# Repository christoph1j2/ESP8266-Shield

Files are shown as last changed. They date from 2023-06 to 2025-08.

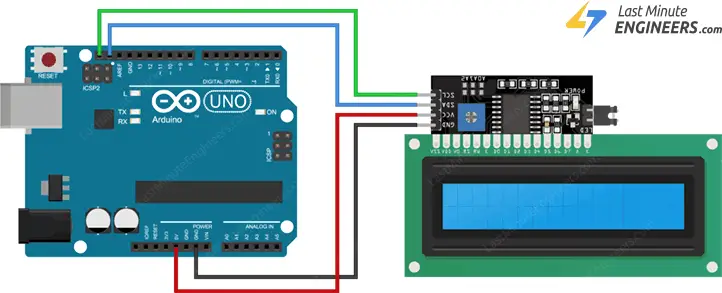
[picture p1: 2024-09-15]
soubory/Wiring-I2C-LCD-Display-with-Arduino.webp

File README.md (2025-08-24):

# ESP8266 Environmental Monitoring Shield

A comprehensive IoT shield for ESP8266 (Wemos D1 R1/R2) that provides environmental monitoring capabilities with multiple sensors, visual indicators, and MQTT connectivity for remote data collection and monitoring.

## 🔋 Features

- **Environmental Sensing**: Temperature monitoring with DS18B20 sensor and light level detection with photoresistor
- **Visual Feedback**: 16-pixel WS2812 LED strip for data visualization and dual status LEDs
- **User Interface**: 16x2 I2C LCD display with rotary encoder navigation and tactile button control
- **Connectivity**: WiFi connectivity with MQTT protocol support for IoT integration
- **Modular Design**: Clean, modular codebase with custom shield library for easy integration and maintenance

## 🛠️ Hardware Components

| Component | Description | Pin Assignment |
|---|---|---|
| **DS18B20** | Waterproof temperature sensor | D0 (ONE_WIRE_BUS) |
| **WS2812** | 16-pixel addressable LED strip | D4 (LED_PIN) |
| **LCD 1602** | I2C 16x2 character display | I2C (SDA/SCL) |
| **Rotary Encoder** | Navigation input device | D6, D7 (ENCODER_PIN1/2) |
| **Push Button** | Menu toggle control | D5 (BUTTON_PIN) |
| **Photoresistor** | Light level sensor | A0 (LDR_PIN) |
| **Status LEDs** | System status indicators | D8, D3 (STATUS_LED_PIN1/2) |

## 📋 Technical Specifications

- **Microcontroller**: ESP8266 (Wemos D1 R1/R2)
- **Operating Voltage**: 3.3V
- **Temperature Range**: -55°C to +125°C (DS18B20)
- **Light Sensing**: 0-1023 ADC range
- **Display**: 16x2 LCD with I2C interface (0x27)
- **LEDs**: 16 individually addressable WS2812 RGB LEDs
- **Communication**: MQTT over WiFi

## 🚀 Quick Start

### Prerequisites

- Arduino IDE with ESP8266 board package
- Required libraries (included in `/shield/knihovny/`):
  - LiquidCrystal_I2C
  - Adafruit_NeoPixel
  - OneWire
  - DallasTemperature
  - ESP8266WiFi
  - PubSubClient

### Installation

1. **Clone the repository**:
   ```bash
   git clone https://github.com/christoph1j2/ESP8266-Shield.git
   cd ESP8266-Shield
   ```

2. **Hardware Setup**:
   - Connect components according to the pin assignments above
   - Refer to `/dokumentace/schema/` for detailed wiring diagrams

3. **Software Configuration**:
   - Open `/shield/shield.ino` in Arduino IDE
   - Update WiFi credentials in the main sketch:
     ```cpp
     const char* ssid = "your_wifi_ssid";
     const char* password = "your_wifi_password";
     const char* mqtt_server = "your_mqtt_broker_ip";
     ```

4. **Upload to ESP8266**:
   - Select your ESP8266 board in Arduino IDE
   - Compile and upload the sketch

## 💡 Usage

### Menu Navigation

The shield features an intuitive menu system:

- **Button Press**: Toggle between menu and measurement mode
- **Encoder**: Navigate between menu options
- **Menu Options**:
  - Measure Light: Display light levels with LED visualization
  - Measure Temperature: Show temperature readings with color-coded LEDs

### LED Visualization

- **Light Measurement**: LED strip displays light intensity (0-8 LEDs per side)
- **Temperature Measurement**: Color-coded temperature indication
- **Status LEDs**: System status and menu state indicators

### MQTT Integration

The shield automatically publishes sensor data to configured MQTT topics for integration with home automation systems, IoT platforms, or data logging services.

## 📁 Project Structure

```
ESP8266-Shield/
├── shield/                    # Main Arduino project
│   ├── shield.ino            # Main sketch file
│   └── knihovny/             # Required libraries
│       └── LeschkaShield/    # Custom shield library
├── dokumentace/              # Documentation
│   ├── fotky/               # Project photos
│   ├── schema/              # Wiring diagrams
│   ├── design/              # Design files
│   └── video/               # Demo videos
└── soubory/                 # Component reference images
```

## 🔧 API Reference

The `LeschkaShield` library provides a clean interface for all shield functionality:

### Core Functions
- `setupStatusLEDs()` - Initialize status LEDs
- `setupLCD()` - Initialize LCD display
- `setupLEDStrip()` - Initialize WS2812 LED strip
- `setupTemperatureSensor()` - Initialize DS18B20 sensor
- `setupButton()` - Initialize push button

### Sensor Reading
- `readTemperature()` - Get temperature in Celsius
- `readLDR()` - Get light level (0-1023)
- `readEncoder()` - Get encoder state
- `readButton()` - Get button state

### Output Control
- `setStatusLEDs(led1, led2)` - Control status LEDs
- `setLEDsForLight(value)` - Visualize light data
- `setLEDsForTemperature(temp)` - Visualize temperature data

## 🤝 Contributing

This project demonstrates professional IoT development practices and modular code architecture. Contributions are welcome for:

- Additional sensor integrations
- Enhanced data visualization
- Protocol extensions (CoAP, HTTP)
- Mobile app integration
- Web dashboard development

## 📄 License

This project is available for educational and commercial use. Please refer to individual library licenses for third-party components.

## 📸 Gallery

### Component References
The `/soubory/` directory contains reference images for all major components including wiring diagrams for the I2C LCD display, DS18B20 temperature sensor, and component specifications for the encoder, WS2812 LED strip, and shield options.

---

*Developed with focus on clean architecture, modularity, and professional IoT development practices.*

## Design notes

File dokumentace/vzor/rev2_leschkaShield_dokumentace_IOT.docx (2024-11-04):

Vyšší odborná škola
a Střední průmyslová škola elektrotechnická
Plzeň, Koterovská 85

Autor práce: Ernst Christoph Leschka

Třída: IV.H

Dne: 05/08/2024

Téma: Vlastní shield pro ESP

# DOKUMENTACE K PROJEKTU IOT

Prohlášení

Prohlašuji, že jsem tuto práci vypracoval samostatně a použil(a) jsem literární prameny a informace, které cituji a uvádím v seznamu použité literatury.

Souhlasím s využitím mé práce učiteli VOŠ a SPŠE Plzeň k výuce.

V Plzni dne: …..................... Podpis: …..........................

Poděkování

Děkuji Mgr. Jiřímu Hautovi za užitečnou zpětnou vazbu k dokumentaci a softwarovému řešení projektu. Také děkuji Ing. Monice Skřivanové za výbornou přípravu na konci třetího ročníku k vyhotovení projektu.

Obsah

# Úvod

Dokumentace se týká custom shieldu na ESP8266, který měří teplotu a taktéž měří svítivost pomocí LDR (Light Dependent Resistor – čili fotorezistor). Cílem této dokumentace je provést čtenáře funkčností jednotlivých komponent a následně řešením, funkcemi a fungováním shieldu, aby tedy bylo jasno co se děje a jak jej použít.

# 1 WeMos D1 R2 UNO ESP8266

Shield je zpracován na mikrokontroler (dále jen MCU) ESP8266, v mém případě specificky na model WeMos D1 R2 UNO ESP8266. Tato MCU mimo jiné na rozdíl například od Arduina umožňuje připojení k Wi-Fi. Jistě si každý povšimne, že na rozdíl od Arduina má méně využitelných pinů, k vyřešení problému nedostatku pinů lze využít expander jako je například PCF8575, který vám pomocí I2C přidá o 16 pinů navíc.

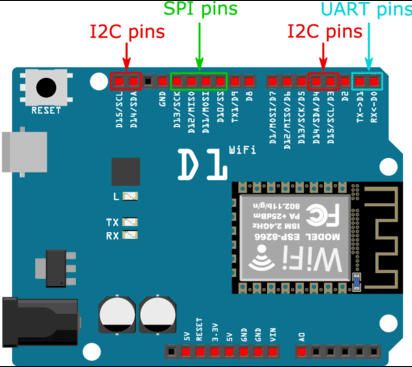
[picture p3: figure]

Obrázek 1: Zobrazení ESP8266 v software Fritzing s popsanými piny [1]

## 1.1 Využití I2C

Neodlučitelnou součástí řešení mého shield je I2C, což je sériový komunikační protokol, který využívá seriál data line (SDA) a seriál clock line (SCL) [2] – viz. Obrázek 1. Nedílná součást shieldu je 16x02 LCD Displej, který komunikuje právě přes I2C. Měl jsem v plánu se taktéž pokusit o vykreslení změny hodnot v čase pomocí grafu na 128x32 OLED displeji, který taktéž komunikuje přes I2C, nicméně se mi bohužel nepodařilo jej zprovoznit. Podobně jsem měl v plánu využít 16bitový expandér pinů PCF8575, jenž taky komunikuje přes I2C, ten jsem ale nakonec nepotřeboval, tak jsem ho z mého řešení eliminoval.

# 2 Hardware řešení

Všechny komponenty jsou na prototypovém shieldu, jelikož si nedokážu představit, jak to zhotovit jinak. Na shieldu jsou přímo připájené LEDky pro zobrazení stavu, enkodér, tlačítko a fotorezistor. Přímo mimo shield leží ještě tepelné čidlo, LCD displej a LED pásky. V podkapitolách bude popis unikátních komponent.

## 2.1 Seznam komponent

Komponenta | Množství | Cena/kus | Link | Cena
Arduino UNO prototype Shield | 1 | 54 Kč | laskakit (https://www.laskakit.cz/arduino-uno-prototype-shield-mini-breadboard/) | 54 Kč
16x2 LCD displej 1602 modrý + I2C převodník | 1 | 98 Kč | laskakit (https://www.laskakit.cz/16x2-lcd-displej-1602-i2c-prevodnik/) | 98 Kč
DS18B20 Digitální vodotěsné čidlo teploty | 1 | 48 Kč | laskakit (https://www.laskakit.cz/dallas-digitalni-vodotesne-cidlo-teploty-ds18b20-1m/) | 48 Kč
8x inteligentní RGB LED NeoPixel pásek, WS2812B | 2 | 28 Kč | laskakit (https://www.laskakit.cz/8x-inteligentni-rgb-led-neopixel-pasek--ws2812b--5050--5v/) | 56 Kč
Fotorezistor 5 mm GL5516 | 1 | 3 Kč | laskakit (https://www.laskakit.cz/fotorezistor-5mm-gl5516/) | 3 Kč
Keyes KY-040 Rotační encoder | 1 | 34 Kč | laskakit (https://www.laskakit.cz/keyes-ky-040-rotacni-encoder-s-tlacitkem/) | 34 Kč
Rezistor 10kΩ | 3 | 1 Kč | laskakit (https://www.laskakit.cz/futaba-1-4w-odpor-10k-5/) | 3 Kč
Rezistor 220Ω | 2 | 1 Kč | laskakit (https://www.laskakit.cz/1-4w-odpor-220r-5/) | 2 Kč
Tlačítko | 1 | 2 Kč | laskakit (https://www.laskakit.cz/tlacitko-6x6x5mm/) | 2 Kč
LED 5 mm | 2 | 1 Kč | laskakit (https://www.laskakit.cz/led-dioda-5mm/?variantId=1130) | 2 Kč
WeMos D1 R2 UNO ESP8266 [^1] | 1 | 178 Kč | laskakit (https://www.laskakit.cz/wemos-d1-r2-uno-esp8266/) | 178 Kč
~~PCF8575 I2C 16 bit I/O~~ ~~Expander~~ [^2] | 1 | 118 Kč | laskakit (https://www.laskakit.cz/pcf8575-i2c-16-bit-i-o-expander/) | 118 Kč
~~0.91" 128x32 OLED displej~~ | 1 | 88 Kč | laskakit (https://www.laskakit.cz/oled-displej-modry-128x32-0-91--i2c/) | 88 Kč
| | | | 686 Kč [^3]

## 2.2 Prototype Shield

Prototype shield je vlastně základ celého shieldu, zjednodušuje konstrukci a po připojení součástek je, lze říci, „Plug-and-Play“. Na ploše shieldu jsou vyhrazená místa pro připojení napájení (5 V) a uzemnění (GND). Taky zde najdeme už připravené tlačítko na reset.

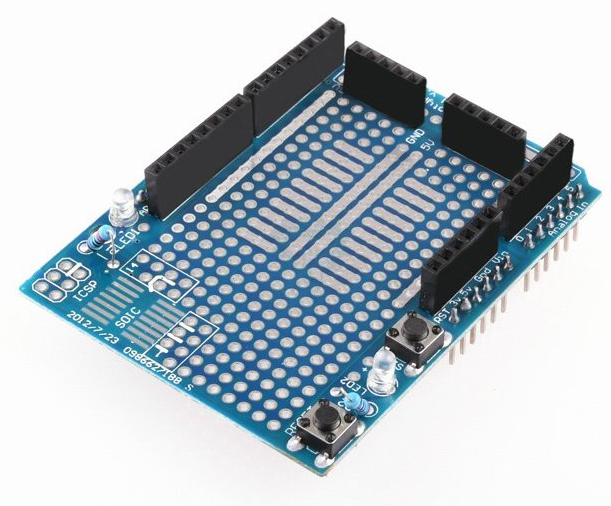
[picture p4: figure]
Obsah obrázku Obvodoví součástka, Elektronická součástka, elektronika, Počítačová komponenta Popis byl vytvořen automaticky

Obrázek 2: Arduino UNO prototype Shield [3]

## 2.3 LCD Displej 16x2 (I2C)

Tento LCD displej má, jak lze poznat podle názvu, rozlišení 16x2, tedy 16 sloupců na dva řádky. Tento displej se primárně používá pro zobrazení znaků či nějakého krátkého textu. V mém případě je to pro zobrazení menu, kde jsou dvě možnosti a poté pro zobrazení hodnoty toho, co právě měříme. Zezadu je potenciometr k úpravě kontrastu.

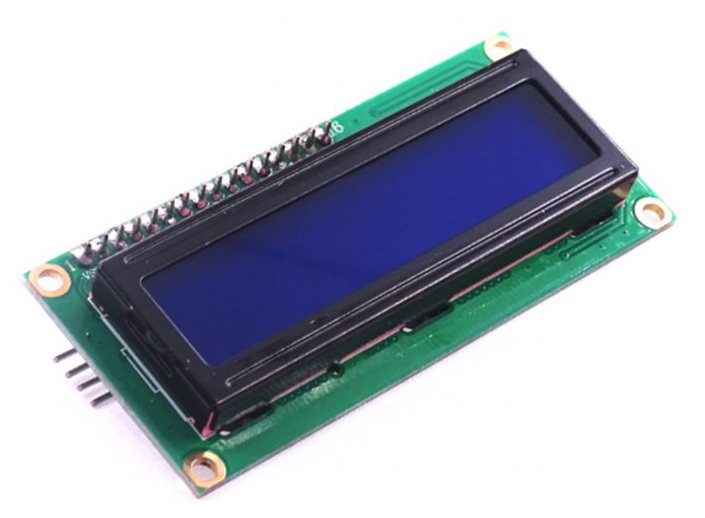
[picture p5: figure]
Obsah obrázku elektronika, Elektronická součástka, Počítačová komponenta, Obvodoví součástka Popis byl vytvořen automaticky

Obrázek 3: 16x2 LCD displej 1602 modrý [4]

### 2.3.1 Schéma zapojení a ukázkový kód I2C 1602 LCD Displeje

V případě I2C verze tohoto displeje je zapojení triviální – uzemnění do GND, napájení VCC do 5 V a následně SDA a SCL do I2C pinů na desce. Na obrázku níže je sice použito Arduino, ale v našem případě zapojení vypadá stejně.

Obrázek 4: I2C zapojení 1602 LCD k Arduinu [5]

Abychom mohli opravdu použít LCD displej musíme použít knihovnu „LiquidCrystal_I2C“, která zahrnuje mnoho funkcí na jeho ovládání. Na obrázku níže vidíme kód, který na první řádce displeje zobrazí text „Hello World!“ a na druhé řádce „LCD Tutorial“. [6]

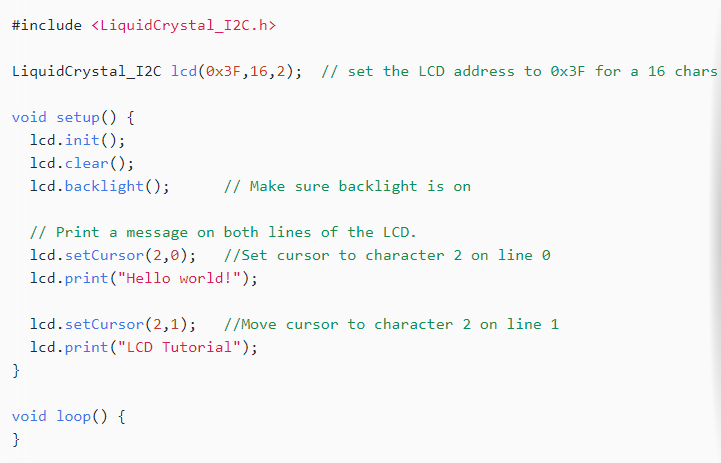
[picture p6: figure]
Obsah obrázku text, snímek obrazovky, Písmo Popis byl vytvořen automaticky

Obrázek 5: Ukázka kódu k LCD [6]

## 2.4 DS18B20 Digitální čidlo teploty

Jedna ze dvou měřených jednotek na shieldu je teplota, tu budeme měřit za pomocí digitálního vodotěsného čidla teploty DS18B20. Čidlo využívá 1wire protokol, který je v principu podobný I2C, ale s nižší rychlostí přenosu dat a delší funkční vzdáleností. [7]

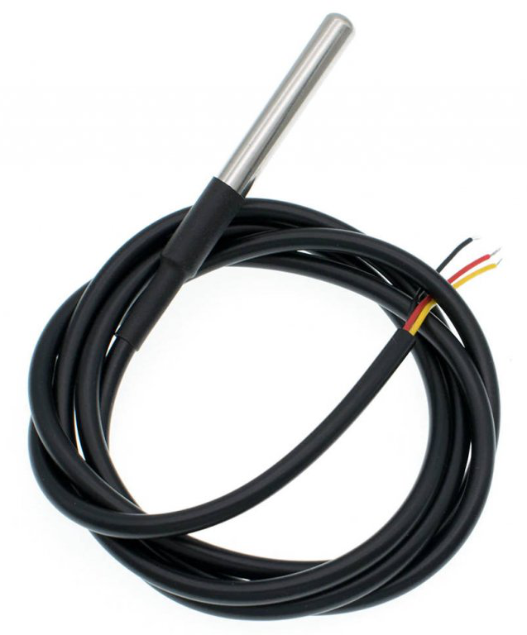
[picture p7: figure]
Obsah obrázku kabel Popis byl vytvořen automaticky se střední mírou spolehlivosti

Obrázek 6: čidlo teploty DS18B20 [8]

### 2.4.1 Schéma zapojení a ukázkový kód DS18B20

Zapojení je intuitivní, uzemnění do GND, napájení VDD do 5 V a datový kabel do digitálního pinu na desce (v případě obrázku D2). Aby přenos dat byl stabilní, přidáme ještě 10kΩ pull-up rezistor mezi datový kabel a napájení.


Obrázek 7: Zapojení čidla teploty k Arduinu [9]

Abychom mohli pomocí čidla měřit, tak budeme potřebovat dvě knihovny – tj. „OneWire“ a „DallasTemperature“. Knihovna OneWire přidává podporu pro 1wire protokol (podobně jako knihovna Wire pro I2C) a knihovna DallasTemperature přidává funkce k ovládání tepelného čidla.

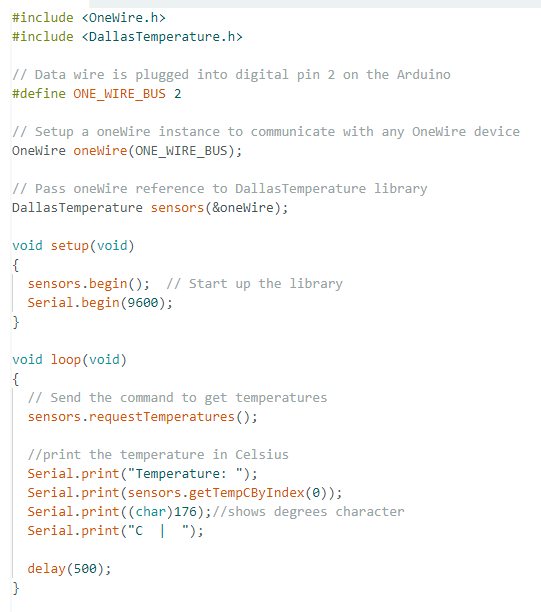
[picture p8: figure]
Obsah obrázku text, snímek obrazovky, Písmo, číslo Popis byl vytvořen automaticky

Obrázek 8: Ukázka kódu k čidlu teploty [10]

## 2.5 RGB LED NeoPixel pásek

Tento LED pásek je tvořen LED diodami WS2812B zapojenými do série. Tyto LED diody mají vestavěný čip s pamětí 3 bajty. Těmi se nastavuje intenzita svitu každé ze tří barev. To umožňuje komunikaci pomocí jednokanálového rozhraní. [11] Pro zobrazení „velikosti“ naměřených hodnotu využijme RGB LED pásku. Při měření světla tedy svítí 0-8 „pixelů“ na pásce podle toho, jakou hodnotu od 0-1024 fotorezistor naměří. Stejně tak u teploty svítí 0-8 „pixelů“ podle toho, jakou hodnotu od -10°C do 70°C naměří tepelné čidlo.

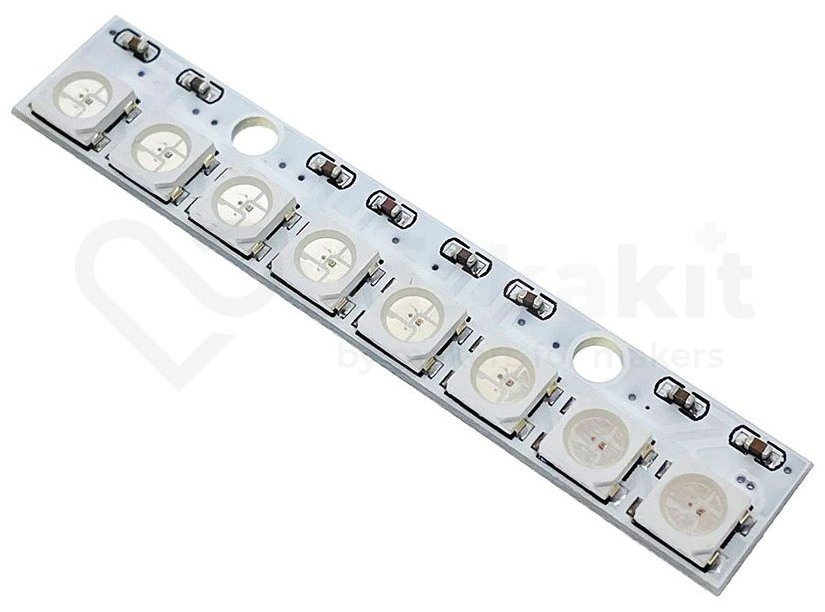
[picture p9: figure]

Obrázek 9: RGB LED NeoPixel pásek [11]

### 2.5.1 Schéma zapojení a ukázkový kód NeoPixel RGB pásku

Opětně triviální zapojení – uzemnění do GND, napájení VCC do 5V a DIN do digital pinu na desce. Chceme-li zapojit více pásek sériově, tak z druhé strany první pásky zapojíme DOUT do druhé pásky DIN.

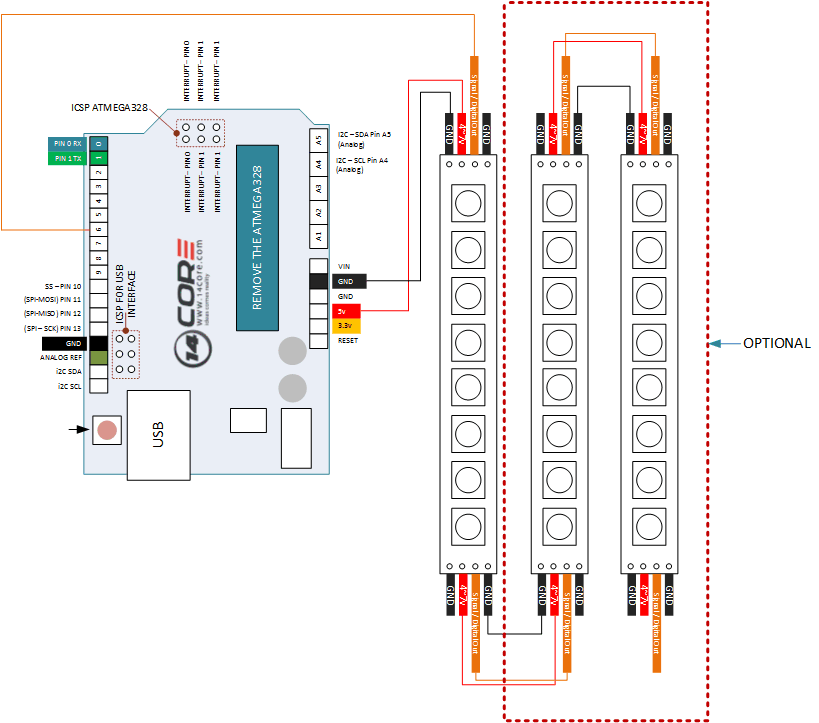
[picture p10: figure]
Obsah obrázku text, diagram, Paralelní, snímek obrazovky Popis byl vytvořen automaticky

Obrázek 10: Zapojení WS2812 LED Pásky [12]

Nyní k ukázce kódu – tento program vytvoří efekt pomalého „nalití“ barvy do pásku dlouhého 1 m s 30 LED/m, bude se cyklicky střídat sedm barev. Po rozsvícení celý pásek plynule pohasne [13]

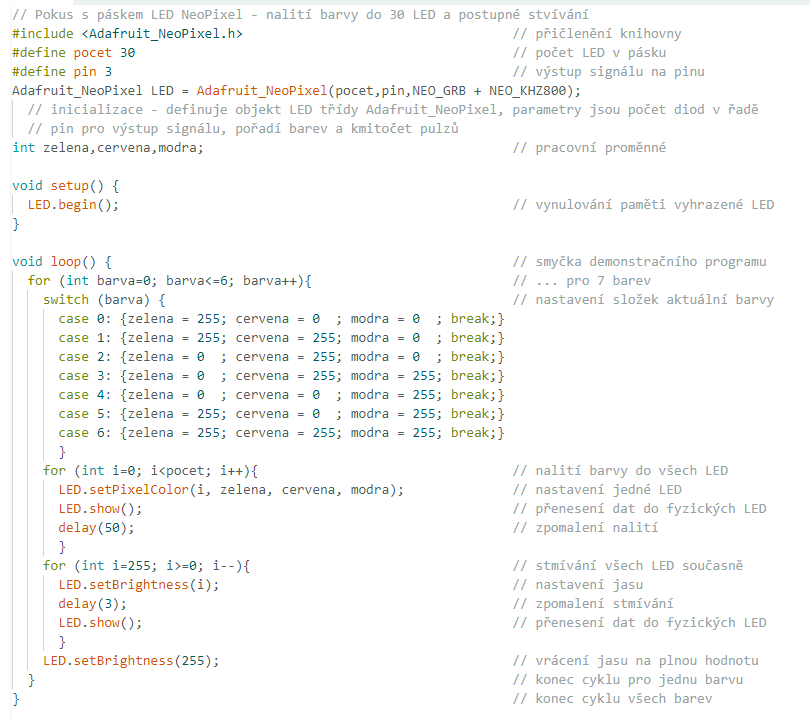
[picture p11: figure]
Obsah obrázku text, snímek obrazovky, číslo, Písmo Popis byl vytvořen automaticky

Obrázek 11: Ukázka kódu k LED pásce [13]

## 2.6 KY-040 Rotační enkodér

Otočný enkodér Keyes KY-040 je rotační vstupní zařízení, které ukazuje, jak moc byl knoflík otočen a jakým směrem se otáčí. Je to skvělá komponenta pro řízení krokových a servomotorů. [14] V našem případě ho využijeme k výběru měřené jednotky v menu.

Obrázek 12: KY-040 Rotační enkodér [15]

### 2.6.1 Schéma zapojení a ukázkový kód enkodéru

Opět nic složitého, uzemnění do GND, napájení do 5V a poté CLK a DT do digital pinů na desce. SW nevyužijeme.

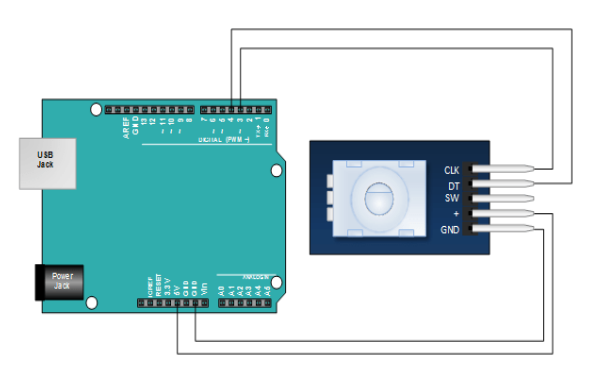
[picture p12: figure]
Obsah obrázku text, Obdélník, snímek obrazovky, design Popis byl vytvořen automaticky

Obrázek 13: Zapojení enkodéru KY-040 do Arduina [14]

Kód testuje klíčové funkce enkodéru, tedy pozici, ve které aktuálně je a možnost zjistit, zda poslední rotace byla ve směru hodinových ručiček či v proti směru. V řešení shieldu takto „komplikovaný“ kód ale nebyl potřeba, jelikož nám stačí dvě hodnoty, tedy např. 1 a 0.

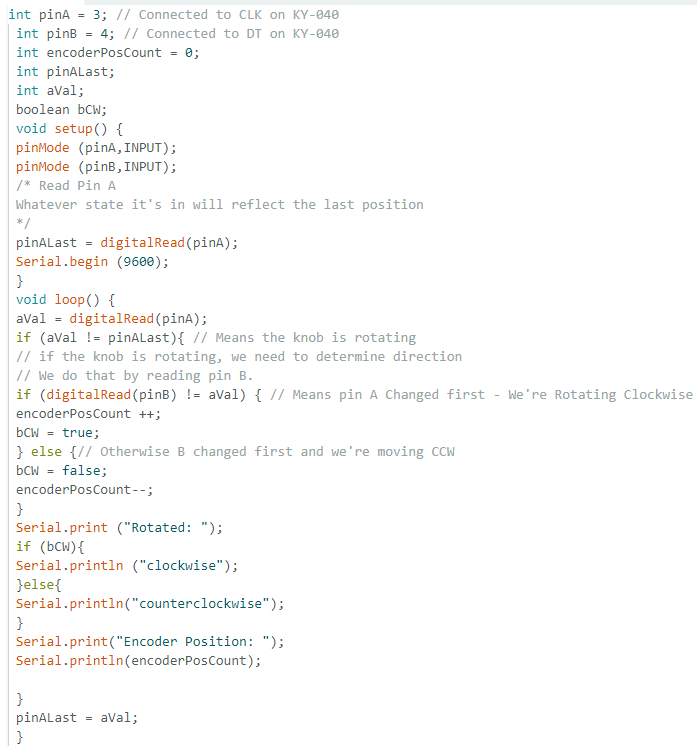
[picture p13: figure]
Obsah obrázku text, snímek obrazovky, dokument Popis byl vytvořen automaticky

Obrázek 14: Ukázka kódu enkodéru KY-040 [14]

## 2.7 Finální hardware řešení shieldu

Poskládáme-li všechny zmíněné komponenty dohromady, vznikne tato finální verze zapojení.

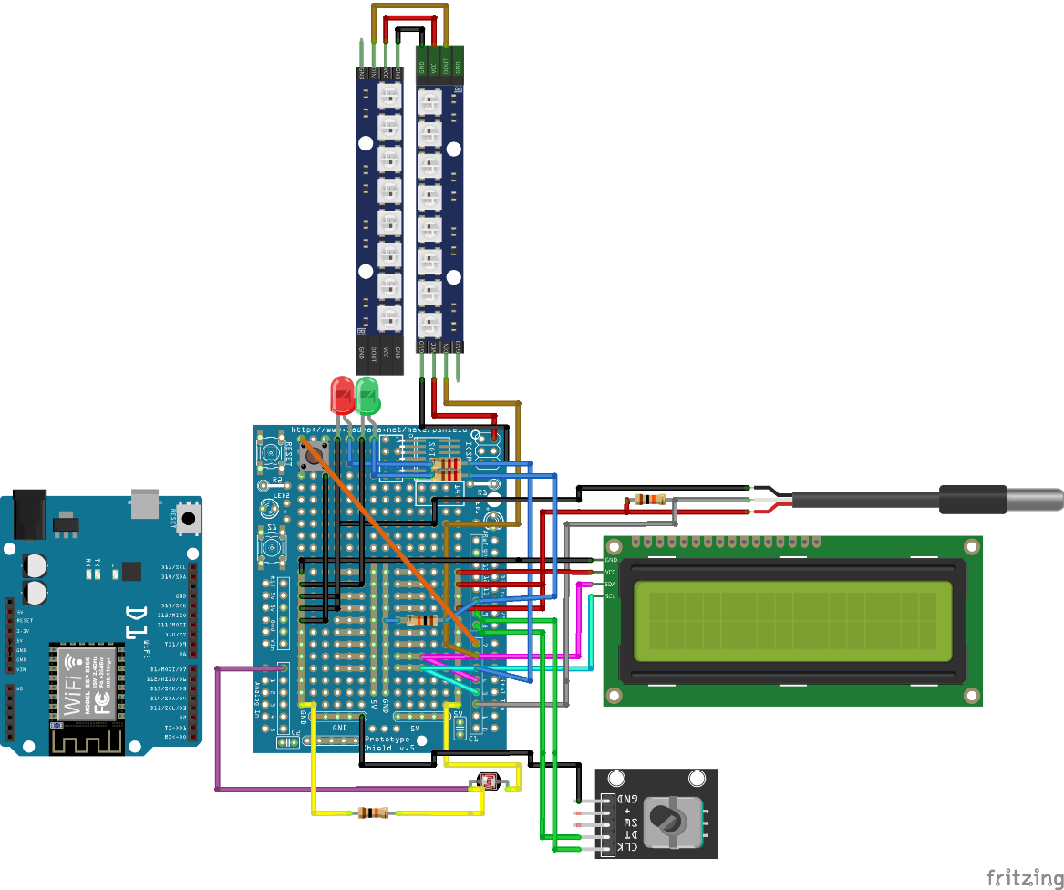
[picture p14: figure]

Obrázek 15: Zapojení shieldu ve Fritzingu [16]

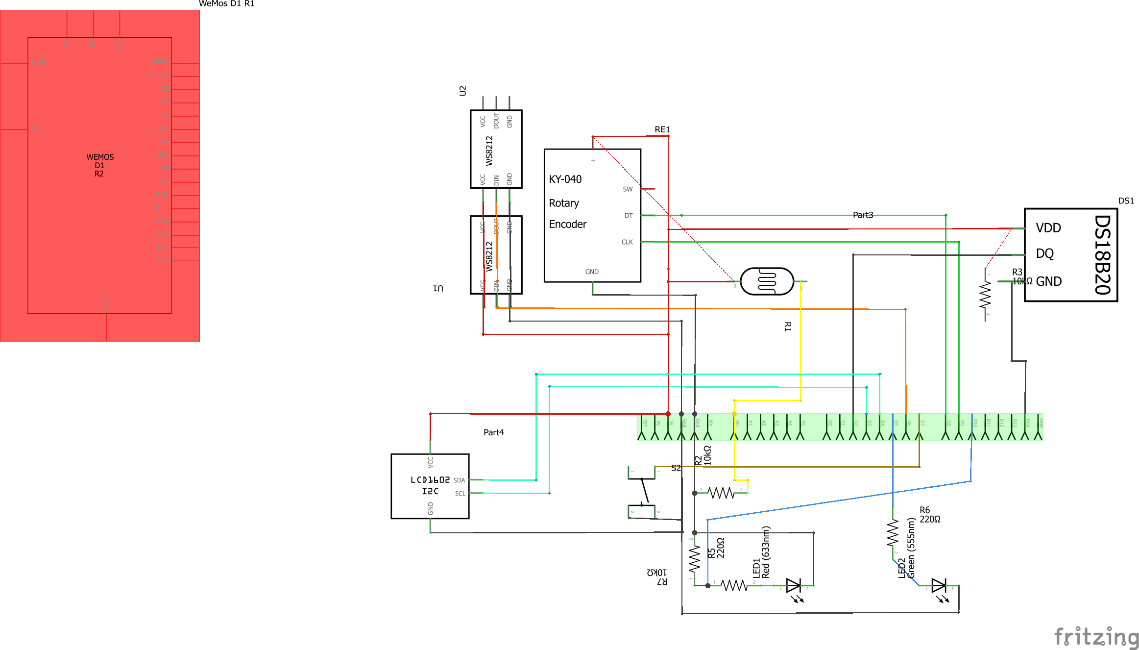
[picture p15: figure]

Obrázek 16: Schéma zapojení shieldu ve Fritzingu [16]

### 2.7.1 Vysvětlení finálního HW řešení

Komponenta | Pin
Červená status LED | D8
Zelená status LED | D3
Enkodér pin 1 | D6
Enkodér pin 2 | D7
LED Pásek | D4
Protokol OneWire (datový pin tepelného čidla) | D0
Tlačítko | D5
Fotorezistor | A0

- Vše spojeno na prototype shieldu, který se zapojí do MCU.
- Dvě LED pásky o 8 LED „pixelech“ spojené v sérii, obě tedy dávají součet 16 LED „pixelů“.
- 10kΩ rezistor u LDR.
- U tlačítka rezistor nevyužijeme, jelikož použijeme zabudovaný pull-up rezistor na desce.
- U červené status LED využijeme navíc 10kΩ rezistor, jelikož je zapojena do digitálního pinu 8, který má speciální vlastnosti.
- Jak jsme již zmínili v kapitole o tepelném čidle, využijeme 10kΩ rezistor mezi datovým pinem a napájením.
- LCD displej je na I2C sběrnici, D2 = SDA; D1 = SCL

# 3 Software řešení

Jelikož v zadání bylo nutností, aby kód byl modulární, tak jsem můj kód modularizoval, jak jen to šlo. Nejprve jsem využil možnosti vytvořit si vlastní knihovnu, ve které budou funkce pro každou komponentu. A v hlavním programu jsem kód modularizoval do funkcí.

## 3.1 Vlastní knihovna „LeschkaShield“

Nejprve začněme vytvořením header souboru, ve kterém budou definované využité potřebné knihovny pro komponenty, konstanty (piny, počet LED na pásce) a objekty (LCD, LED Pásek, tepelné čidlo) včetně deklarace funkcí, které využijeme v C++ souboru knihovny.

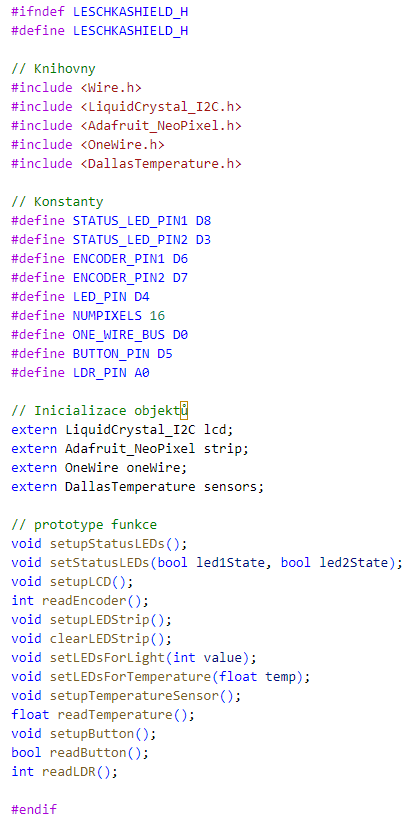
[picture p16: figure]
Obsah obrázku text, snímek obrazovky, Písmo, dokument Popis byl vytvořen automaticky

Obrázek 17: Kód v header souboru "LeschkaShield.h" [16]

V C++ souboru nejprve přiřadíme hodnoty objektům inicializovaným v header souboru.

Obrázek 18: Objekty v LeschkaShield.cpp [16]

Poté vytvoříme všechny funkce, které chceme, aby knihovna zahrnovala. V mém případě jsem vytvořil nejprve setup funkci ke každé komponentě, tj. „setupStatusLEDs()“, „setupLCD()“, „setupLEDStrip()“, „setupTemperatureSensor()“ a „setupButton()“, tyto funkce v hlavním programu vložíme do „setup()“ a máme to z krku.

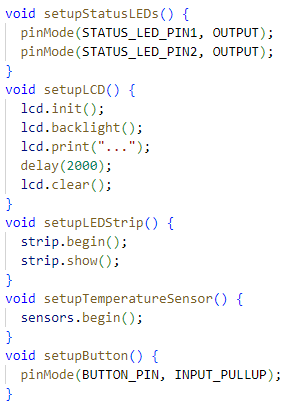
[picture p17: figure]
Obsah obrázku text, snímek obrazovky, Písmo, číslo Popis byl vytvořen automaticky

Obrázek 19: setup funkce v LeschkaShield.cpp [16]

A následně jsem vytvořil již funkce, které „něco dělají“, tj. „setStatusLEDs()“, „readEncoder()“, „clearLEDStrip()“, „setLEDsForLight()“, „setLEDsForTemperature()“, „readTemperature()“, „readButton()“ a „readLDR()“. Tyto funkce si probereme detailněji.

### 3.1.1 Funkce „void setStatusLEDs(bool led1State, bool led2State)“

Funkce bere dva bool parametry, tj. led1State a led2State, které určí, zda má LED svítit či nikoliv.

Obrázek 20: Funkce setStatusLEDs [16]

### 3.1.2 Funkce „int readEncoder()“

Funkce int readEncoder() vrací z pinu enkodéru buď 1 nebo 0, jelikož máme v menu jen dvě možnosti, tak jiné hodnoty nepotřebujeme.

Obrázek 21: Funkce readEncoder [16]

### 3.1.3 Funkce „void clearLEDStrip()“

Funkce, jak lze poznat podle názvu, jenom „vyčistí“, čili vypne LED pásek pomocí funkcí z knihovny „Adafruit_NeoPixel.h“.

Obrázek 22: Funkce clearLEDStrip [16]

### 3.1.4 Funkce „void setLEDsForLight(int value)“

Funkce rozsvítí x LED na pásku podle toho, jakou hodnotu naměří LDR (parametr value). Namapuje tedy hodnotu z LDR mezi 0–8, nastaví barvu a poté pomocí cyklu for na obou páscích zároveň rozsvítí 0-8 LED podle naměřené hodnoty.

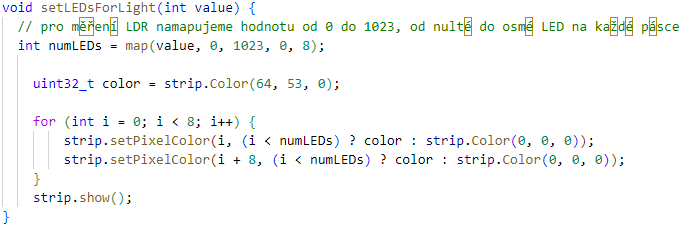
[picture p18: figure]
Obsah obrázku text, snímek obrazovky, Písmo, řada/pruh Popis byl vytvořen automaticky

Obrázek 23: Funkce setLEDsForLight [16]

### 3.1.5 Funkce „void setLEDsForTemperature(float temp)“

Funkce rozsvítí x LED na pásku podle toho, jakou hodnotu naměří tepelné čidlo (parametr temp). Namapuje tedy hodnotu z čidla (-10 °C–80 °C) mezi 0–8, barvu nastaví podle počtu zapnutých LED – modrou, svítí-li dvě či méně, zelenou svítí-li šest či méně a červenou, svítí-li sedm či více. Stejně jako u předchozí funkce pomocí cyklu for na obou páscích zároveň rozsvěcuje 0–8 LED podle naměřené hodnoty.

Obrázek 24: Funkce setLEDsForTemperature [16]

### 3.1.6 Funkce „float readTemperature()“

Pomocí funkcí z knihovny „DallasTemperature.h“ vrátí desetinnou hodnotu teploty.

Obrázek 25: Funkce readTemperature [16]

### 3.1.7 Funkce „int readLDR()“

Funkce vrací hodnotu načtenou z pinu LDR.

Obrázek 26: Funkce readLDR [16]

### 3.1.8 Funkce „bool readButton()“

Tato funkce zajišťuje správnou funkčnost tlačítka.

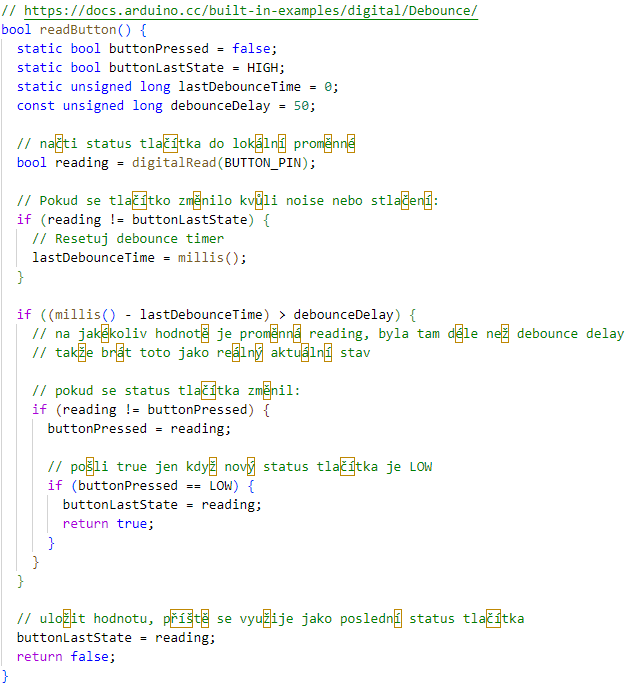
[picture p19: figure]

Obrázek 27: Funkce readButton [17]

## 3.2 Hlavní program

Jelikož jsme si vytvořením knihovny zjednodušili hlavní sketch, tak nám stačí importovat knihovnu, vytvořit pár QoL funkcí (modularizace), zajistit logiku v setup a loop funkcích a nahrát.

### 3.2.1 Funkce „void buttonPress(bool& inMenu, int& menuIndex)“

Funkce mění stav proměnné inMenu, zajišťuje správné zobrazení na LCD displeji a vypíná LED pásek, pokud jsme v menu.

Obrázek 28: Funkce buttonPress [16]

### 3.2.2 Funkce „void displayMenu(int menuIndex)“

Funkce čte hodnotu z enkodéru, dle které vizuálně na displeji ukáže, zda je právě zvolena možnost měření světla či teploty. Taktéž aktualizuje LED statusu.

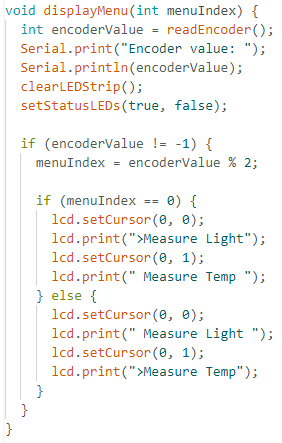
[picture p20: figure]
Obsah obrázku text, snímek obrazovky, Písmo, číslo Popis byl vytvořen automaticky

Obrázek 29: Funkce displayMenu [16]

### 3.2.3 Funkce „void menuSelection(int menuIndex)“

Funkce zobrazí na monitoru právě měřenou veličinu podle hodnoty z enkodéru, taky aktualizuje LED statusu.

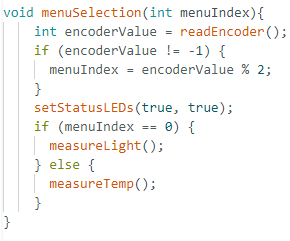
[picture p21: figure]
Obsah obrázku text, snímek obrazovky, Písmo, číslo Popis byl vytvořen automaticky

Obrázek 30: Funkce menuSelection [16]

### 3.2.4 Funkce „void measureLight()“

Funkce načte hodnotu z LDR, zobrazí jej na LCD a rozsvítí adekvátní počet LED na pásce.

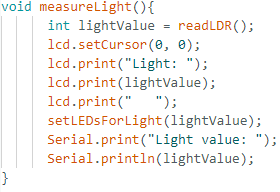
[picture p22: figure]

Obrázek 31: Funkce measureLight [16]

### 3.2.5 Funkce „void measureTemp()“

Funkce načte hodnotu z tepelného čidla, zobrazí jej na LCD a rozsvítí adekvátní počet LED na pásce.

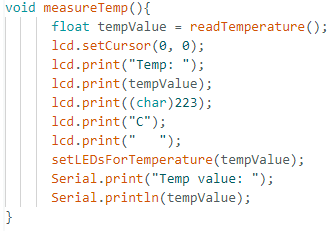
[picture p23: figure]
Obsah obrázku text, snímek obrazovky, Písmo, číslo Popis byl vytvořen automaticky

Obrázek 32: Funkce measureTemp [16]

### 3.2.6 Funkce „void setup()“

Konečně se dostáváme k hlavním funkcím hlavního programu, v setup jen zavoláme setup funkce z naší knihovny.

Obrázek 33: Funkce setup [16]

### 3.2.7 Funkce „void loop()“

A nakonec, jelikož jsme si kód modularizovali i v hlavním programu, tak je loop velice zjednodušený.

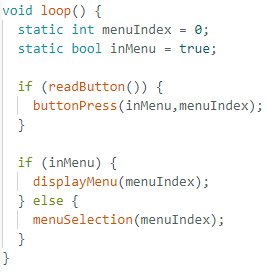
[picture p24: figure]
Obsah obrázku text, snímek obrazovky, Písmo, číslo Popis byl vytvořen automaticky

Obrázek 34: Funkce loop [16]

# 4 Finální podoba řešení projektu vlastní shield

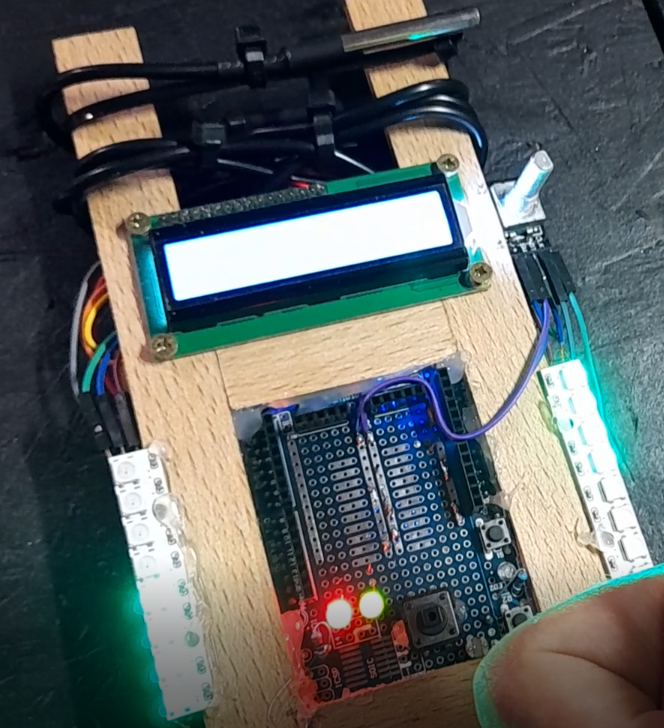
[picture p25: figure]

Díky správnému návrhu schéma zapojení a modularizaci kódu skrz knihovnu a funkce vše fungovalo tak, jak má.

Obrázek 35: Finální řešení [16]

# Závěr

Tento projekt mě naučil mnohého – mezi hlavní poznatky patří primárně vytvoření knihovny a práce s I2C (přestože jsem I2C již využil v projektu „Model Dopravní Situace“, tak jsem se naučil podrobněji, jak funguje). Samozřejmě nemohu opominout ten fakt, že jsem hlouběji porozuměl komponentám a hlavně ESP8266 (neměl jsem možnost ve škole, jelikož jsem byl na stáži v Německu). Naopak se mi bohužel nepovedlo zprovoznit OLED displej, který měl na sobě míti graf.

# Seznam použité literatury

[1] - DEBAJYOTI, Biswas. A WiFi-based Self-Organizing Multi-Hop Sensor Network for Internet of Things. Online. In: Research Gate. 2021. Dostupné z: https://www.researchgate.net/figure/The-UART-I2C-and-SPI-pins-of-a-wemos-D1-R2-ESP8266_fig3_350940118. [cit. 2024-08-09].

[2] - TEXAS INSTRUMENTS. A Basic Guide to I2C. Online. 2022. Dostupné z: https://www.ti.com/lit/an/sbaa565/sbaa565.pdf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,and%20receive%20commands%20and%20data.. [cit. 2024-08-09].

[3] - Arduino UNO prototype Shield + mini BreadBoard. Online. C2024. Dostupné z: https://www.laskakit.cz/arduino-uno-prototype-shield-mini-breadboard/. [cit. 2024-08-10].

[4] - 16x2 LCD displej 1602 modrý. Online. C2024. Dostupné z: https://www.laskakit.cz/16x2-lcd-displej-1602-i2c-prevodnik/. [cit. 2024-08-10].

[5] - Wiring an I2C LCD Display to an Arduino. Online. C2024. Dostupné z: https://lastminuteengineers.com/i2c-lcd-arduino-tutorial/. [cit. 2024-08-10].

[6] - Basic Arduino Sketch – Hello World. Online. C2024. Dostupné z: https://lastminuteengineers.com/i2c-lcd-arduino-tutorial/. [cit. 2024-08-10].

[7] - 1-Wire. Online. In: Wikipedia: the free encyclopedia. San Francisco (CA): Wikimedia Foundation, 2001-. Dostupné z: https://en.wikipedia.org/wiki/1-Wire. [cit. 2024-08-10].

[8] - DS18B20 Digitální vodotěsné čidlo teploty 1m. Online. C2024. Dostupné z: https://www.laskakit.cz/dallas-digitalni-vodotesne-cidlo-teploty-ds18b20-1m/#relatedFiles. [cit. 2024-08-10].

[9] - Wiring a DS18B20 Temperature Sensor to an Arduino. Online. C2024. Dostupné z: https://lastminuteengineers.com/ds18b20-arduino-tutorial/. [cit. 2024-08-10].

[10] - Arduino Example Code. Online. C2024. Dostupné z: https://lastminuteengineers.com/ds18b20-arduino-tutorial/. [cit. 2024-08-10].

[11] - 8x inteligentní RGB LED NeoPixel pásek, WS2812B, 5050, 5V. Online. C2024. Dostupné z: https://www.laskakit.cz/8x-inteligentni-rgb-led-neopixel-pasek--ws2812b--5050--5v/#ratingTab. [cit. 2024-08-10].

[12] - Wiring WS2812 8-Bit RGB LED Strip with Arduino. Online. C2024. Dostupné z: https://www.14core.com/wiring-ws2812-8-bit-rgb-led-strip-with-arduino/. [cit. 2024-08-10].

[13] - LED NeoPixel – jak na ně s Arduinem. Online. C2024. Dostupné z: https://robodoupe.cz/2015/led-neopixel-jak-na-ne-s-arduinem/. [cit. 2024-08-10].

[14] - KY-040 Arduino Rotary Encoder User Manual. Online. C2024. Dostupné z: https://www.epitran.it/ebayDrive/datasheet/25.pdf. [cit. 2024-08-11].

[15] - Keyes KY-040 Rotační encoder s tlačítkem bez závitu. Online. C2024. Dostupné z: https://www.laskakit.cz/keyes-ky-040-rotacni-encoder-s-tlacitkem-bez-zavitu/. [cit. 2024-08-11].

[16] – Vlastní zdroj

[17] - Debounce on a Pushbutton. Online. 2015, 09/02/2022. Dostupné z: https://docs.arduino.cc/built-in-examples/digital/Debounce/. [cit. 2024-08-10].

# Seznam obrázků, tabulek a grafů

[^1] MCU není nedílnou součástí shieldu, ale shield je na tuto MCU, tudíž dává smysl ho dát do ceny
[^2] Přeškrtnutý text = v konečném řešení součástka není, avšak byla v plánu a je zmíněna v textu
[^3] Cena včetně komponent, které buď nejsou nedílnou součástí shieldu nebo nejsou součástí vůbec

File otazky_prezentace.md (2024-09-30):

# Otázky na prezentaci
**Zodpovězte prosím pro třídu pravdivě následující otázky**
| otázka | vyjádření |
| :--- | :--- |
| jak dlouho mi tvorba zabrala - **čistý čas** | 6h |
| jak se mi to podařilo rozplánovat | docela dobře, začal jsem Fritzingem, skončil jsem hotovým produktem |
| design zapojení |https://imgur.com/a/gD2YWdw |
| proč jsem zvolil tento design | v rámci možností mi tento design dával největší smysl |
| zapojení | https://imgur.com/a/7QyiuHO |
| z jakých součástí se zapojení skládá | prototype shield, lcd displej, ds18b20 čidlo teploty, 2x RGB LED pásek, fotorezistor, enkodér KY-040 |
| realizace | https://imgur.com/a/gNO8HE5 |
| nápad, v jakém produktu vše propojit dohromady| nějaké měřidlo fyzikálních veličin v domácnosti(?) |
| co se mi povedlo | ten fakt, že to funguje a že jsem nemusel dělat po revizi drastické změny |
| co se mi nepovedlo/příště bych udělal/a jinak | "čistota" zapojení |
| zhodnocení celé tvorby | 8.5/10 |

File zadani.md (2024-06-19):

# Vlastní desky/shield
**Zadání: Rozmyslete, navrhněte, vytvořte, otestujte a vytvořte dokumentaci k vlastnímu shield**

Motivace - v 4r se budeme zabývat zejména datovými toky, tedy si připravíme shield ke zjednodušení načítání/indikaci dat.

## Termíny
| milník | termín | týdnů |
|:- | :- | -:|
| Zadání | **19.6.**  | 0 |
| Dokumentace v1 + repo | **17.9.-21.9.** | 13 |
| Vytvořený produkt | **23.9.-27.9.** | 14 |
| Termín prezentace + dokumentace v2 | **30.9.-4.10.** | 15 |

### Ganttův diagram postupu
```mermaid
gantt
    title Milníky projektu
    dateFormat  YYYY-MM-DD
    section Zadání
    Zadání                    :a1, 2024-06-19, 5d
    section Dokumentace
    Dokumentace v1 + repo     :a2, 2024-09-17, 5d
    Dokumentace v2            :a3, 2024-09-30, 5d
    section Vytvoření produktu
    Vytvoření produktu        :a4, 2024-09-23, 5d
    section Prezentace
    Prezentace + video        :a5, 2024-09-30, 5d
```

## Minimální požadavky
* vytvoření shieldu pro ESP (Wemos D1 R1/R2)
* **vytvoření dokumentace - podle vzoru**
  * dodržení formálních požadavků na dokumentaci
  * popis vlastností shieldu
  * zapojení
    * Fritzing
    * schéma
  * ukázkový kód - modulární
* vhodný vlastní reprezentativní design

## Funkčnost shield
* LED indikátor stavu
  * varianty 
    * RG / RB / RYG LEDs semafor
* RGB
  * varianty
    * ARGB pásek WS2812 nebo obdobný WS2812
    * 2 x RGB LED
* LCD 1602 I2C display nebo obdobný
* DS18B20 čidlo kabel
  * ds18b20
* fotorezistor
* volitelně:
  * enkodér
    * pro nastavení PWM/procházení menu
    * encoder

Možnost postavit na předpřipraveném shield
* protoShield
* terminalShield

## Dokumentace
* GIT repo
  * shield
      * průvodní dokument - vypracovaný ze vzoru
      * Fritzing
        * zdroj
        * obrázek
      * elektrotechnické schéma
      * fotky modulů
        * celkový
        * detaily
      * modulární zdrojový kód
        * pro každou součástku napsat, vyzkoušet, zdokumentovat kód
        * napsat tak, aby se jednotlivé moduly daly skládat dohromady (funkce/knihovny/třídy)
        * nastavit si správně piny
    * **odzdrojovat převzaté části**
  * fotky
    * minimálně 5 fotek zapojení jednotlivých částí
    * z toho alespoň jedna fotka kompletního produktu
  * video
    * vložené video/odkaz na video
    * délka min. 1 minutu (ne delší než 1:30)
      * ukázka funkčnosti
      * ukázka designu
      * ukázka procesu tvorby
      * z čeho je produkt sestaven
      * (efekty, hudba, humor - volitelně)
  * design

## Výstup
* produkt splňující minimální požadavky
* odevzdaná (tištěná) dokumentace
* GIT repo
* odkaz na vlastní GIT repo vložený do tabulky na společném repo
* prezentace funkčnosti před třídou
* video prezentující projekt o délce min. 1 minuty, ne delší než 1:30

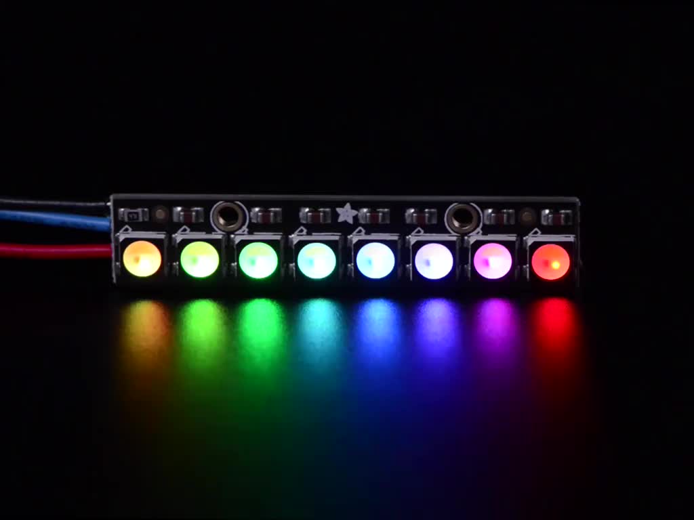
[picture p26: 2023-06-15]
soubory/ws2812.jpg

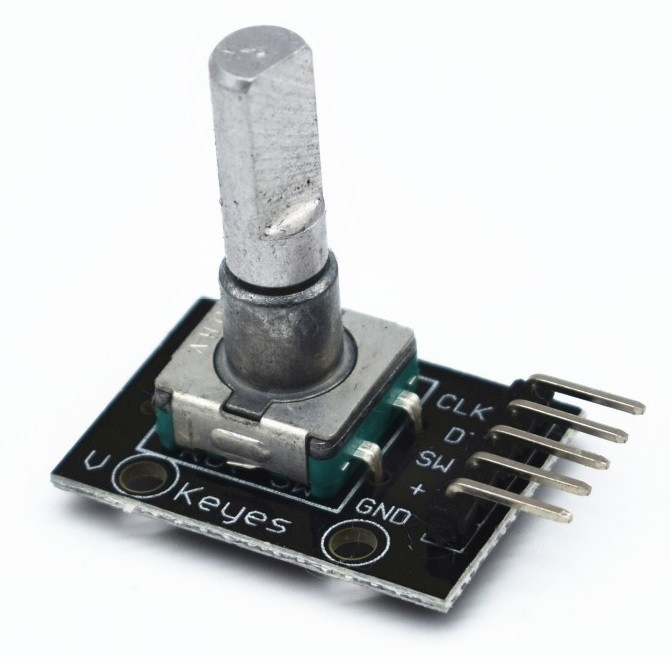
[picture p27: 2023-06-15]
soubory/encoder.jpg

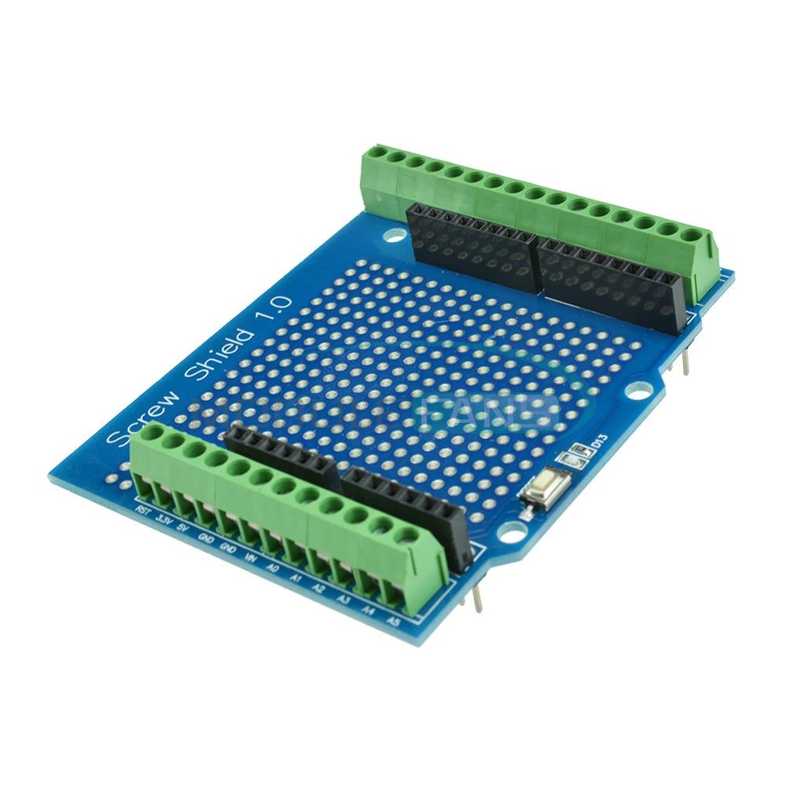
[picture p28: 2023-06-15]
soubory/protoShield.jpg

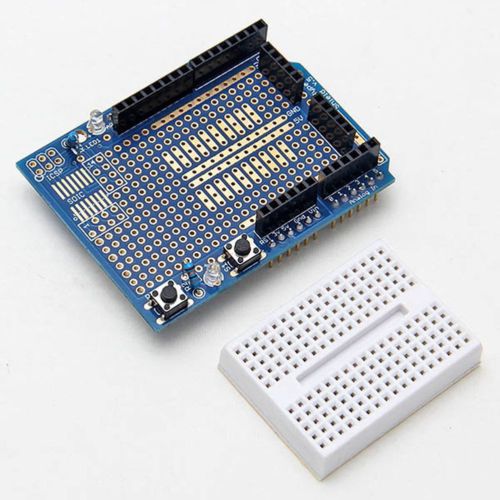
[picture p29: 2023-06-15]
soubory/terminalShield.jpg

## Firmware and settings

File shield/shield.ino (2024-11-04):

#include "LeschkaShield.h"

//mqtt
WiFiClient espClient;
const char* ssid = "3301-IoT";
const char* password = "mikrobus";
const char* mqtt_server = "10.202.31.211";
PubSubClient client(espClient);
unsigned long lastMsg = 0;
#define MSG_INTERVAL 2000

void buttonPress(bool& inMenu, int& menuIndex){
    Serial.println("Button pressed");
    inMenu = !inMenu;
    lcd.clear();
    if (inMenu) {
      clearLEDStrip();
    }
}

void displayMenu(int menuIndex) {
  int encoderValue = readEncoder();
  Serial.print("Encoder value: ");
  Serial.println(encoderValue);
  clearLEDStrip();
  setStatusLEDs(true, false);

  if (encoderValue != -1) {
    menuIndex = encoderValue % 2;

    if (menuIndex == 0) {
      lcd.setCursor(0, 0);
      lcd.print(">Measure Light");
      lcd.setCursor(0, 1);
      lcd.print(" Measure Temp ");
    } else {
      lcd.setCursor(0, 0);
      lcd.print(" Measure Light ");
      lcd.setCursor(0, 1);
      lcd.print(">Measure Temp");
    }
  }
}

void menuSelection(int menuIndex){
    int encoderValue = readEncoder();
    if (encoderValue != -1) {
      menuIndex = encoderValue % 2;
    }
    setStatusLEDs(true, true);
    if (menuIndex == 0) {
      measureLight();
    } else {
      measureTemp();
    }
}

void measureLight(){
      int lightValue = readLDR();
      lcd.setCursor(0, 0);
      lcd.print("Light: ");
      lcd.print(lightValue);
      lcd.print("   ");
      setLEDsForLight(lightValue);
      Serial.print("Light value: ");
      Serial.println(lightValue);
}

void measureTemp(){
      float tempValue = readTemperature();
      lcd.setCursor(0, 0);
      lcd.print("Temp: ");
      lcd.print(tempValue);
      lcd.print((char)223);
      lcd.print("C");
      lcd.print("   ");
      setLEDsForTemperature(tempValue);
      Serial.print("Temp value: ");
      Serial.println(tempValue);
}

void setup() {
  Serial.begin(115200);

  // zavolá setup metody z knihovny LeschkaShield.h
  setupStatusLEDs();
  setupLCD();
  setupButton();
  setupLEDStrip();
  setupTemperatureSensor();

  // mqtt
  setup_wifi();
  client.setServer(mqtt_server, 1883);
  client.setCallback(callback);
}

void loop() {
  static int menuIndex = 0;
  static bool inMenu = true;

  // Zajištění připojení k MQTT brokeru
  if (!client.connected()) {
    reconnect();
  }
  client.loop();

  // Ovládání menu
  if (readButton()) {
    buttonPress(inMenu, menuIndex);
  }

  if (inMenu) {
    displayMenu(menuIndex);
  } else {
    menuSelection(menuIndex);
  }

  // Odesílání teploty a LDR hodnoty
  unsigned long now = millis();
  if (now - lastMsg > MSG_INTERVAL) {
    lastMsg = now;
    
    // Odeslání hodnoty LDR
    char lightMsg[50];
    snprintf(lightMsg, 50, "%ld", readLDR());
    client.publish("4hs2/leschkae/ESP/ldr", lightMsg);

    // Odeslání hodnoty teploty
    char tempMsg[50];
    snprintf(tempMsg, 50, "%.2f", readTemperature());
    client.publish("4hs2/leschkae/ESP/temp", tempMsg);

    Serial.println("Data odeslána na MQTT server.");
  }
}

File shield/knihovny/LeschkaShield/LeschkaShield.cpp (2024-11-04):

#include "LeschkaShield.h"

// objekty
LiquidCrystal_I2C lcd(0x27, 16, 2);
Adafruit_NeoPixel strip = Adafruit_NeoPixel(NUMPIXELS, LED_PIN, NEO_GRB + NEO_KHZ800);
OneWire oneWire(ONE_WIRE_BUS);
DallasTemperature sensors(&oneWire);

void setupStatusLEDs() {
  pinMode(STATUS_LED_PIN1, OUTPUT);
  pinMode(STATUS_LED_PIN2, OUTPUT);
}

void setStatusLEDs(bool led1State, bool led2State) {
  digitalWrite(STATUS_LED_PIN1, led1State ? HIGH : LOW);
  digitalWrite(STATUS_LED_PIN2, led2State ? HIGH : LOW);
}

void setupLCD() {
  lcd.init();
  lcd.backlight();
  lcd.print("...");
  delay(2000);
  lcd.clear();
}

int readEncoder() {
  // čteme jen encoderpin1, jelikož nepotřebujeme jinou hodnotu než 1 nebo 0
  return digitalRead(ENCODER_PIN1);
}

void setupLEDStrip() {
  strip.begin();
  strip.show();
}

void clearLEDStrip() {
  strip.clear();
  strip.show();
}

void setLEDsForLight(int value) {
  // pro měření LDR namapujeme hodnotu od 0 do 1023, od nulté do osmé LED na každé pásce
  int numLEDs = map(value, 0, 1023, 0, 8);

    uint32_t color = strip.Color(64, 53, 0); // Reduced brightness

    for (int i = 0; i < 8; i++) {
        strip.setPixelColor(i, (i < numLEDs) ? color : strip.Color(0, 0, 0));
        strip.setPixelColor(i + 8, (i < numLEDs) ? color : strip.Color(0, 0, 0));
    }
    strip.show();
}

void setLEDsForTemperature(float temp) {
  // pro měření teploty napamujeme hodnotu od -10 do 70, abychom mohli vizuálně vidět nějakou změnu na páskách
  int numLEDs = map(temp, -10, 70, 0, 8);
  uint32_t color = strip.Color(0, 0, 0);

  // logika pro barvu LED
  if (numLEDs <= 2) {
    // svítí-li dvě či méně (nízká teplota), bude barva modrá
    color = strip.Color(0, 64, 64);  // modrá
  } else if (numLEDs <= 6) {
    // svítí-li šest či méně (normální teplota), bude barva zelená
    color = strip.Color(0, 64, 0);  // zelená
  } else {
    // jinak červená (vysoká teplota)
    color = strip.Color(64, 0, 0);  // červená
  }

  for (int i = 0; i < 8; i++) {
    // obě pásky nezávisle na sobě se rozsvicují podle teploty
    strip.setPixelColor(i, (i < numLEDs) ? color : strip.Color(0, 0, 0));
    strip.setPixelColor(i + 8, (i < numLEDs) ? color : strip.Color(0, 0, 0));
  }
  strip.show();
}

void setupTemperatureSensor() {
  sensors.begin();
}

float readTemperature() {
  sensors.requestTemperatures();
  return sensors.getTempCByIndex(0);
}

void setupButton() {
  pinMode(BUTTON_PIN, INPUT_PULLUP);
}

// https://docs.arduino.cc/built-in-examples/digital/Debounce/
bool readButton() {
  static bool buttonPressed = false;
  static bool buttonLastState = HIGH;
  static unsigned long lastDebounceTime = 0;
  const unsigned long debounceDelay = 50;

  // načti status tlačítka do lokální proměnné
  bool reading = digitalRead(BUTTON_PIN);

  // Pokud se tlačítko změnilo kvůli noise nebo stlačení:
  if (reading != buttonLastState) {
    // Resetuj debounce timer
    lastDebounceTime = millis();
  }

  if ((millis() - lastDebounceTime) > debounceDelay) {
    // na jakékoliv hodnotě je proměnná reading, byla tam déle než debounce delay
    // takže brát toto jako reálný aktuální stav

    // pokud se status tlačítka změnil:
    if (reading != buttonPressed) {
      buttonPressed = reading;

      // pošli true jen když nový status tlačítka je LOW
      if (buttonPressed == LOW) {
        buttonLastState = reading;
        return true;
      }
    }
  }

  // uložit hodnotu, příště se využije jako poslední status tlačítka
  buttonLastState = reading;
  return false;
}

int readLDR() {
  return analogRead(LDR_PIN);
}

// MQTT

/* ssid = "3301-IoT";
password = "mikrobus";
mqtt_server = "10.202.31.211"; */

void setup_wifi(){
  delay(10);

  // Připojení k WiFi
  Serial.println();
  Serial.print("Připojování k ");
  Serial.println(ssid);

  WiFi.mode(WIFI_STA);
  WiFi.begin(ssid, password);

  while (WiFi.status() != WL_CONNECTED){
    delay(500);
    Serial.println(".");
  }

  randomSeed(micros());

  Serial.println("");
  Serial.println("WiFi connected");
  Serial.println("IP Address: ");
  Serial.println(WiFi.localIP());
}

void reconnect() {
  // loop než se znovupřipojení zdaří
  while(!client.connected()){
    Serial.print("Pokus o MQTT připojení...");
    //náhodný clientID
    String clientId = "ESP8266Client-";
    clientId += String(random(0xfff), HEX);
    //pokus o připojení
    if(client.connect(clientId.c_str())){
      Serial.println("connected");
      //po připojení vydat announcement
      client.publish("4hs2/laces/ESP", "hello world");
      //...a znovu subscribnout
      //???
      client.subscribe("4hs2/laces/ESP/LED");
    } else {
      Serial.print("failed, rc=");
      Serial.print(client.state());
      Serial.println(" zkus to znova za 5 vterin");
      delay(5000);
    }
  }
}

void callback(char* topic, byte* payload, unsigned int length){
  Serial.print("Zpráva přišla [");
  Serial.print(topic);
  Serial.print("] ");
  for(int i = 0; i<length;i++){
    Serial.print((char)payload[i]);
  }
  Serial.println();

  if((char)payload[0]=='1'){
    digitalWrite(BUILTIN_LED,LOW);
  }
  else {
    digitalWrite(BUILTIN_LED,HIGH);
  }
}
